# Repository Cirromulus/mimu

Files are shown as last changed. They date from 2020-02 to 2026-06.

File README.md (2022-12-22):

# Microphone Mute
Range Sensor for auto-muting a microphone when not in use.

## Description
On stage, noise level is high. A gate on the mics is sometimes not sufficient.
This device is intended to be mounted directly on the back of the mic, sensor facing towards mic.
The trigger-distance is adjustable by pressing the top button.
Also, by double-pressing this button, different mute-profiles will be selectable where choices can be the on- or the off-ramp time, and the dampening (gate/expander) in "mute" mode (testing required).

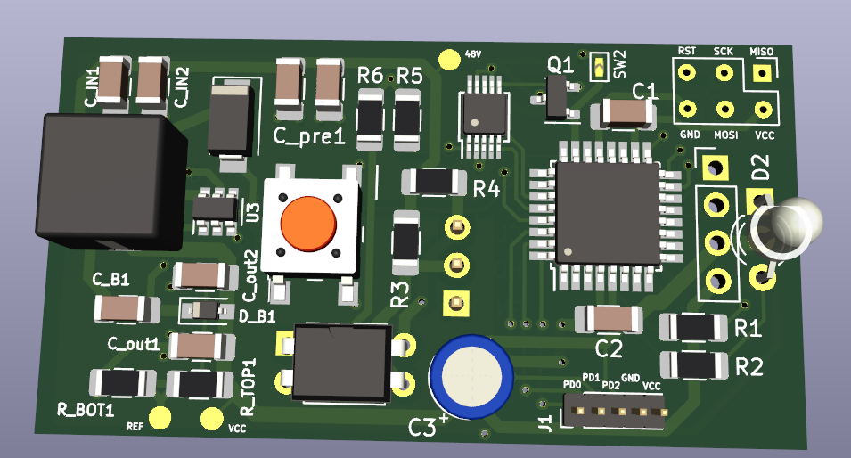
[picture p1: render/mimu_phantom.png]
phantom


## BOM
Main Features:
- ATtiny88 Processor
- GY-530 IR TOF Distance Sensor (VL53L0X)
- PC817 Optocoupler as an attenuator
- AD5258 digi-potentiometer as a variable current control for the Opto

For complete list, see [BOM](pcb/mimu_phantom_bom.html)

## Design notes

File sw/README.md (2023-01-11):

framework-arduino-avr-attiny needs patching if less RAM is desired:

Go to your version of platformio packages (most likely `/home/$(whoami)/.platformio/packages/framework-arduino-avr-attiny`) and apply the patch there (`git apply path-to-patch`).

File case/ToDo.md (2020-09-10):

Für V1:
- X Poti Position passt nicht 
- X Spiel Batteriefach sehr gering, etwas erhöhen
- X Statt Fenster vorne jew ein Loch für Tof und LED, und diese etwas höher als ursprüngliches Fenster
- X Tof weiter nach vorne setzen, Tasche innen dort kleiner
-(X) Verbinder aus dem Weg bei Kabeln->erhöhen. Am besten schraube nach oben rechts versetzen wegen Spaltmaße
- X Durchmesser Verbinder erhöhen, fallen nach und nach vom Rest ab
- X Innendurchmesser ring etwas größer 0,2 oder so
- (X) Nut und Feder für Deckel <- wackelig
- X Tasche im Deckel für Batteriefach Verbreitern, damit das auch passt
- (X) Außerdem Platine etwas "höher" setzen, damit das auch in der Tiefe wirklich passt [-> nächstes Design]
- X Wandstärke Deckel doch wieder etwas hoch, sehr wabbelig
- X Kanten außen alle etwas abrunden
- X Durchmesser Durchgangslöcher noch etwas größer, schrauben bleiben stecken
- X Spiel Schalter leicht geringer
- X Hinteren Stecker etwas weiter raus, weil sonst Konterschrauben mit Innenleben nicht mehr passen

Für V2:
- in zukünfitger Version metallene Einbaubuchse von HiCon nehmen?
- Allgemeinen Parameter für Spiel
- Wichtige Parameter im Zentralteil anlegen
- Gehäuse aufbauen um Stecker / ToF herum

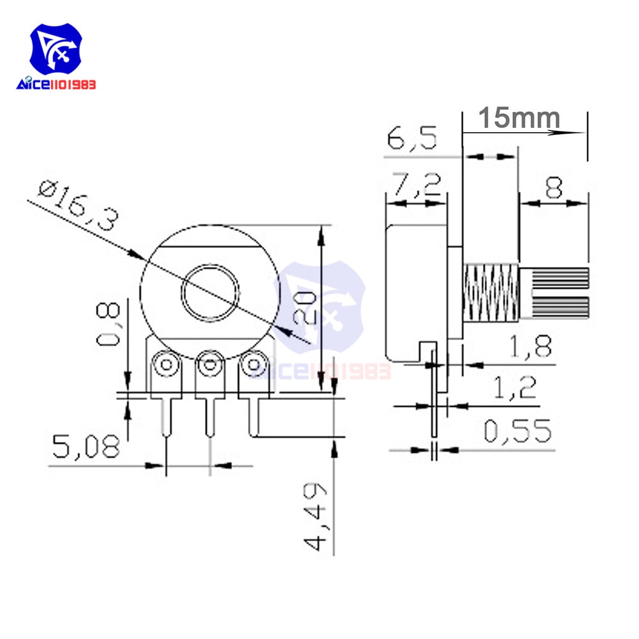
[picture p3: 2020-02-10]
doc/5-PCS-Lot-Potentiometer-Resistor-1K-2K-5K-10K-20K-50K-100K-500K-Ohm-3-Pin.jpg

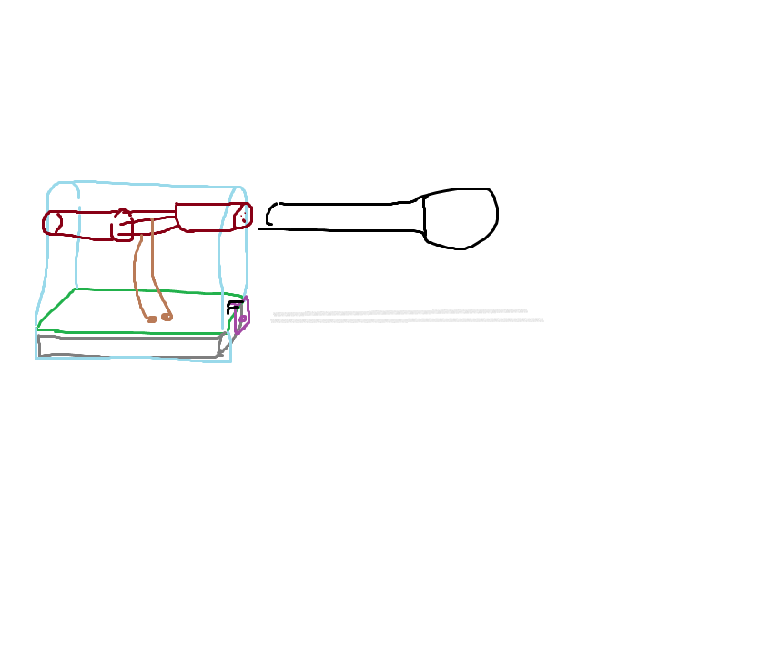
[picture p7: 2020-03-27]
case/totally_accurate_drawing.png

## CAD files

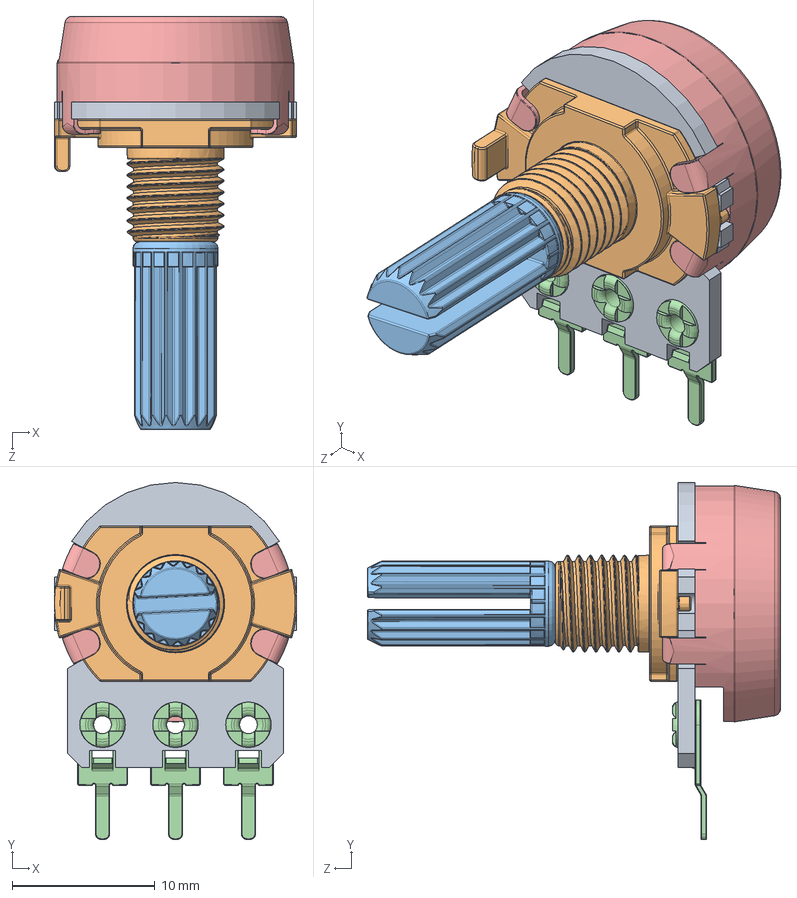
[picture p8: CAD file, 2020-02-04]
pcb/3dFiles/Assem1.SLDASM
17.0 x 25.1 x 29.0 mm
pcb board
base metal
rotating rod metal
pin x 3
sheild metal
plastic base

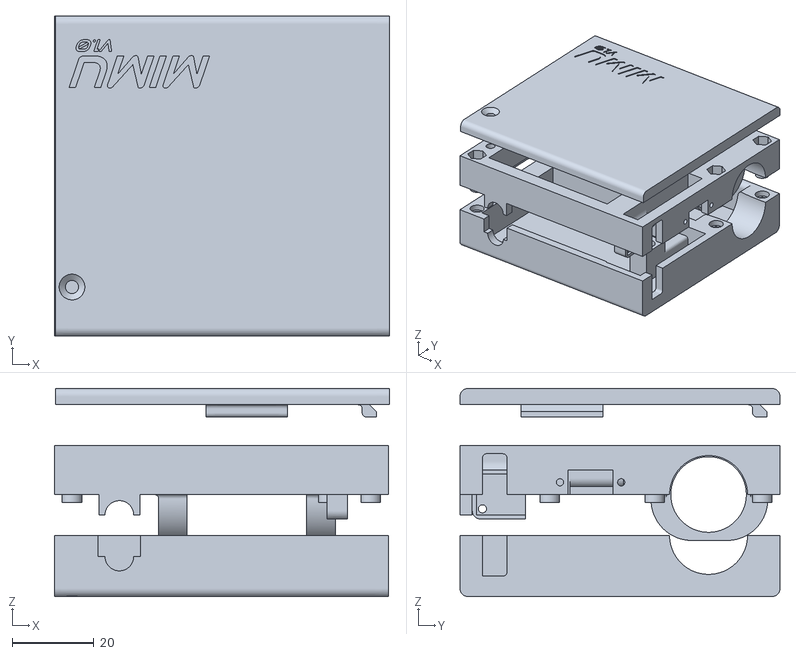
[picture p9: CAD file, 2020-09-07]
case/AssemblyV1.stl
82.1 x 78.4 x 51.0

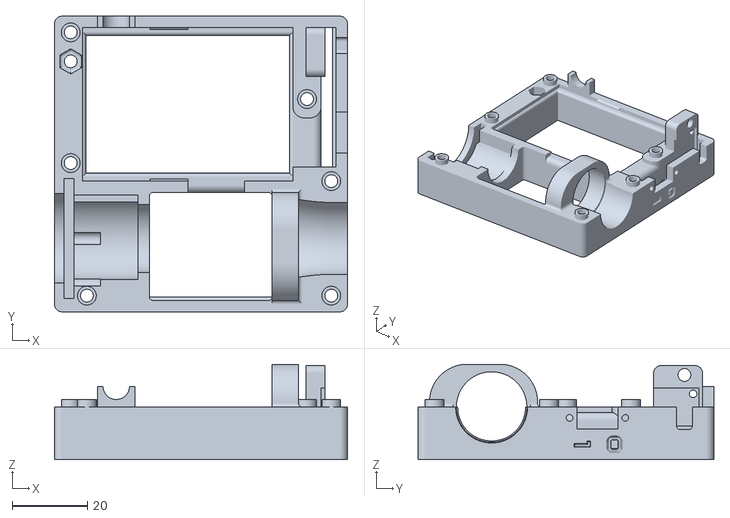
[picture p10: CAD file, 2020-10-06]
case/Gehause_A_neu_Buchse.stl
77.8 x 78.5 x 25.4

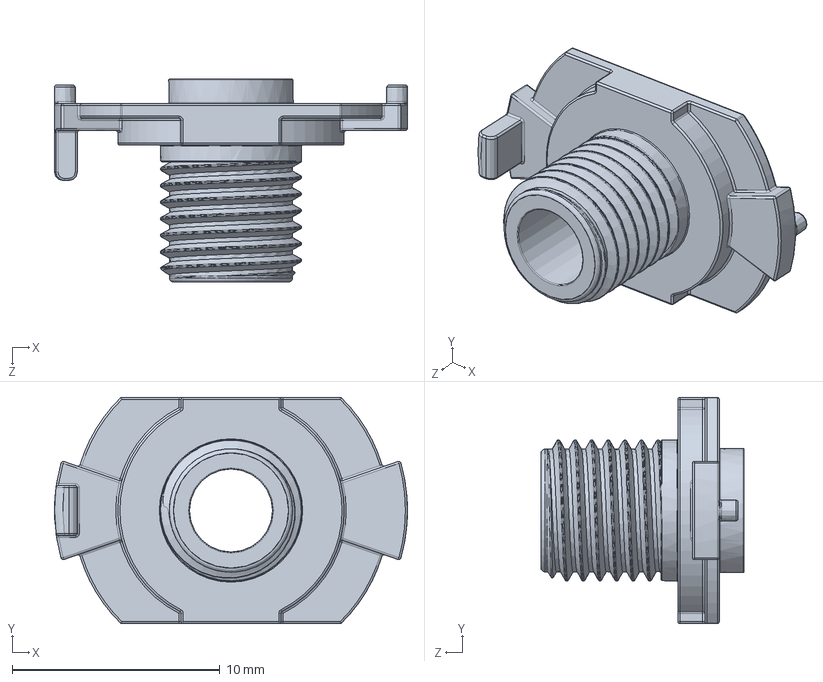
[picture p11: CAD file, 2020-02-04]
pcb/3dFiles/base metal.SLDPRT
17.0 x 10.9 x 9.80 mm

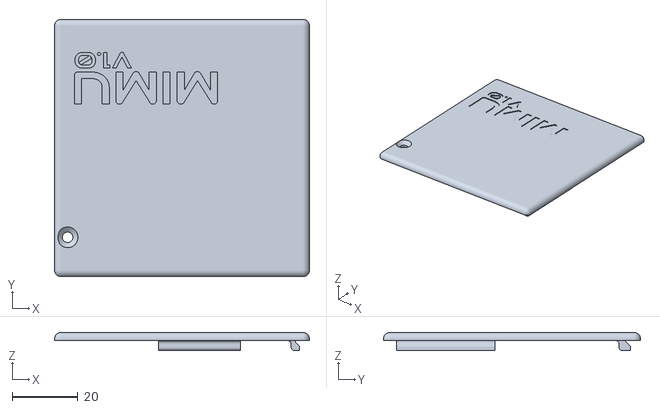
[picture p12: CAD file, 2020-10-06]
case/Deckel.stl
77.8 x 78.5 x 5.50

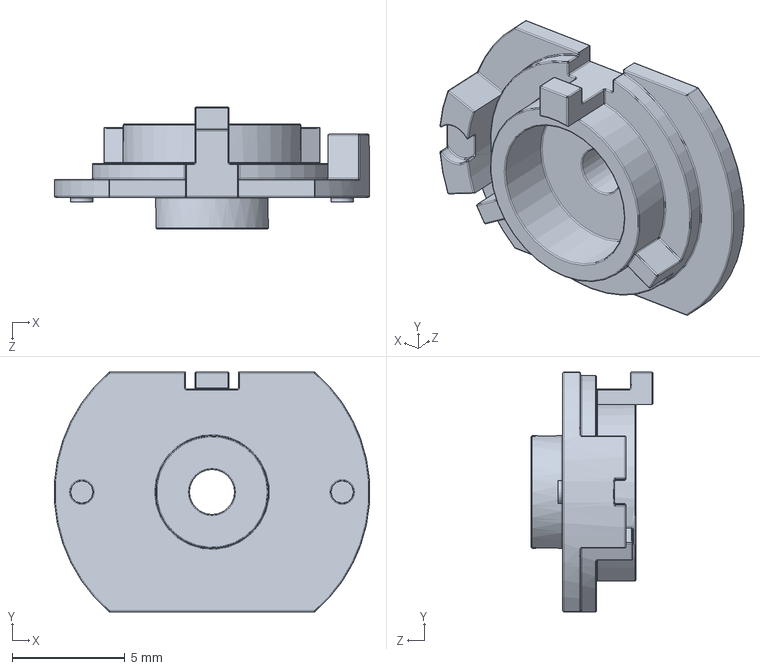
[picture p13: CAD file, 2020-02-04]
pcb/3dFiles/plastic base.SLDPRT
14.0 x 10.6 x 5.40 mm

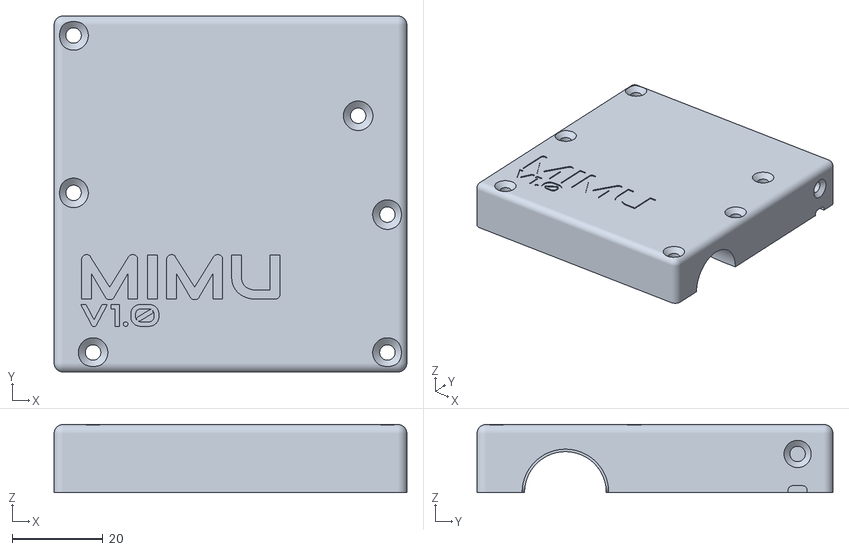
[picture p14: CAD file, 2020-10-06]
case/Gehause_B_Buchse.stl
77.8 x 78.5 x 15.0

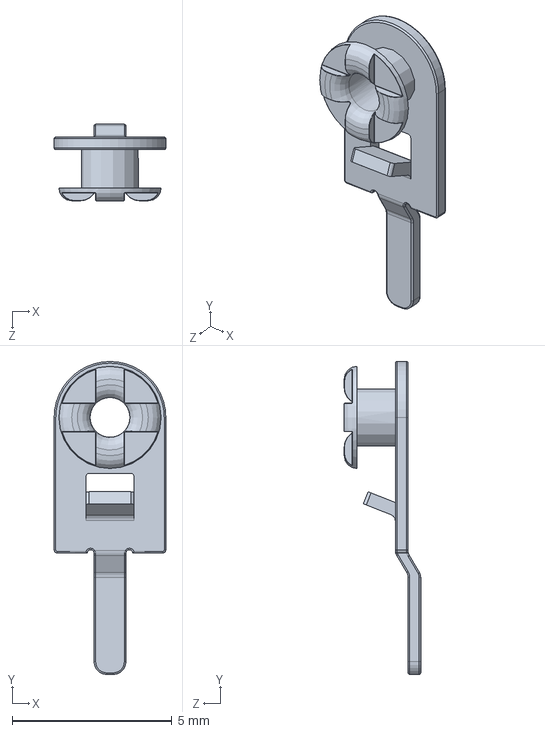
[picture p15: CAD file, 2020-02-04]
pcb/3dFiles/pin.SLDPRT
3.50 x 9.80 x 2.40 mm

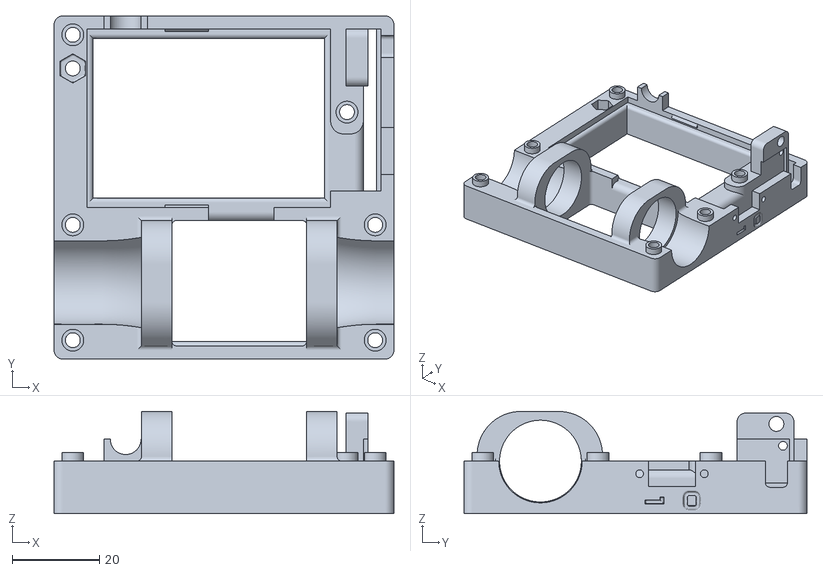
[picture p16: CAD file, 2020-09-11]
case/Gehause_A_neu.stl
77.8 x 78.5 x 23.4

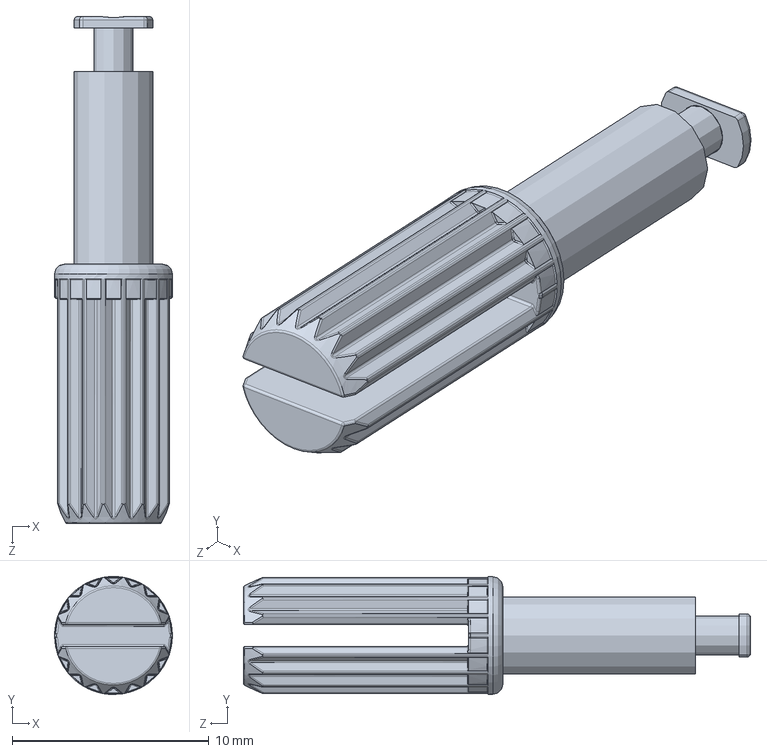
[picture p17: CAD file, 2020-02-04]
pcb/3dFiles/rotating rod metal.SLDPRT
6.00 x 6.00 x 25.8 mm

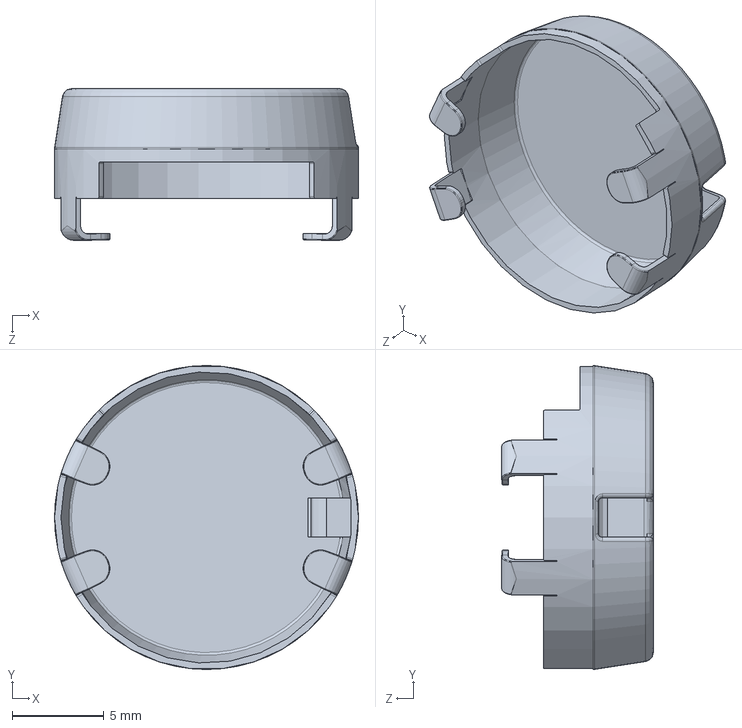
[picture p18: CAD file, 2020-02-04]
pcb/3dFiles/sheild metal.SLDPRT
16.6 x 16.6 x 8.28 mm

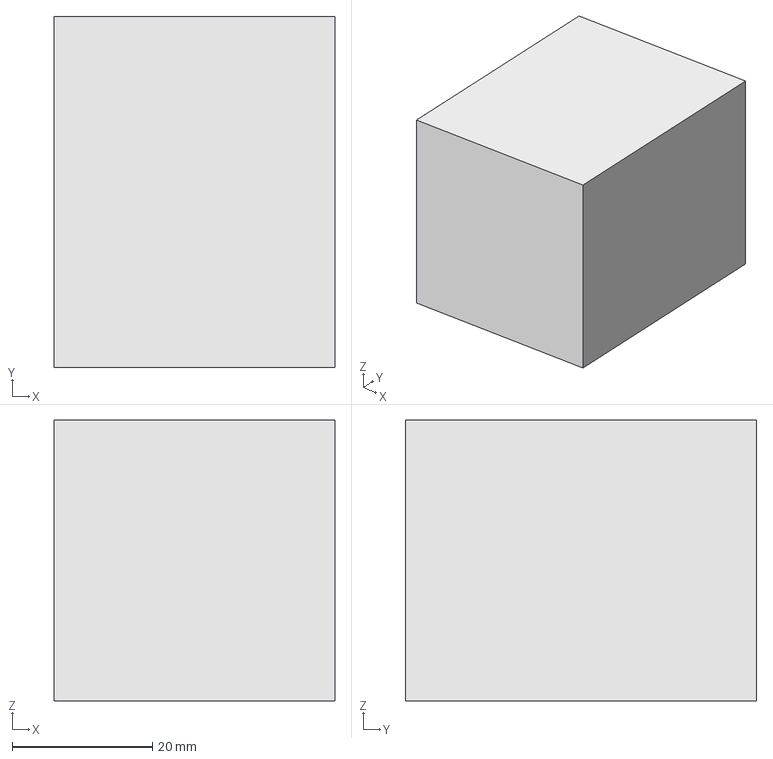
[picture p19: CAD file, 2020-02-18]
case/test.FCStd
40.0 x 50.0 x 40.0 mm

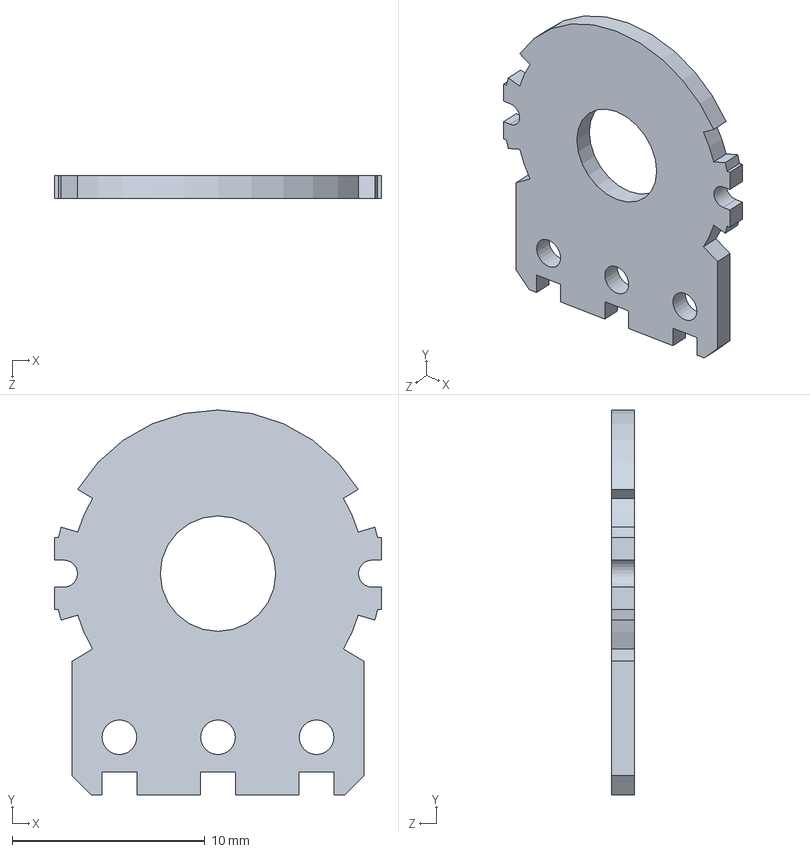
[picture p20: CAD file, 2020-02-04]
pcb/3dFiles/pcb board.SLDPRT
17.0 x 20.0 x 1.20 mm

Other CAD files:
case/Gehause_B.stl

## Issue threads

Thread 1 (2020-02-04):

Schematic & PCB Rendering not easily accessible

cajt, 2020-02-04:
A bitmap export of the Kicad project might make the data more accessible.

Cirromulus, 2020-02-05:
Hi Carl :)
Do you mean something additional to the PCB rendering in /render/board3d.png?
It should be included in the Readme.md .

cajt, 2020-02-07:
The new /render/schematic.png does the job well, and it is way more comfortable that cloning and loading Kicad in the correct version. Thanks!

Closed 2020-02-07.

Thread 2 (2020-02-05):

Button needed

Cirromulus, 2020-02-05:
Sometimes the user may want to deactivate the system without having to disconnect the Batteries.

Cirromulus, 2020-02-12:
added switch breaker

Closed 2020-02-12.

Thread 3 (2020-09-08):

Add automatic calibration routine upon startup

Hackbraten, 2020-09-08:
The Potentiometer is cool and swifty (nice bro that had this idea), but not very user intuitive.
Maybe we reduce the power of the people and just add an automatic calibration routine in startup, that estimates the threshold distance (plus some margin).

Less user errors, less BOM. And BOM is everything.

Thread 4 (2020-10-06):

implement "auto off" function for power saving?

Hackbraten, 2020-10-06:
maybe after x minutes of same tof value or something

Cirromulus, 2020-10-06:
While this is technically possible, I am unsure if a wakeup-latency of ~1s is acceptable on stage.
If this is wanted, an implementation would be feasible.

Cirromulus, 2020-10-06:
While this is technically possible, I am unsure if a wakeup-latency of ~1s is acceptable on stage.
If this is wanted, an implementation would be feasible.

Closed 2020-10-24.

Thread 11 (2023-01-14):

Allow multiple Mute Profiles

Cirromulus, 2023-01-14:
In EEPROM.
How to switch them?
- Double-press button

How to set them?
- Tiny PCB switches, future NFC?

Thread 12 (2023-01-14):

Correct Pad size for Button

Cirromulus, 2023-01-14:
Button is solderable, but pads are a bit not-far apart.

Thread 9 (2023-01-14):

[PCB] Add cap to extra_drive MOSFET output

Cirromulus, 2023-01-14:
The switching Mosfet causes a (faint) cracking noise in Microphone audio.
Perhaps reduce ramp-on time (off time seems ok)

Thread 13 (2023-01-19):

Current draw too high for Phantom Supply

Cirromulus, 2023-01-19:
High draw of Optocoupler is too much.
Even with R_phantom at 1kOhm, supply from Mixing Console is not enough.

Solutions:
- Use more expensive, but less power-hungry Optocoupler `NSL-32SR3`
- Switch to virtual Ground supply (with, perhaps, Opamp `ADA4099-1BUJZ-RL7`) and directly use Digipot (which then has to be higher resistance and logarithmic)

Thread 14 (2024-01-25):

Caustics

tradephonic, 2024-01-25:
Hi there, really sorry to open an issue on an unrelated repo. I was wondering if you could enable issues on https://github.com/Cirromulus/causticsEngineering if you are still willing/able to fix bugs for it. I have been testing the caustics it produces in Blender and found a couple of issues. These issues are not found in the original script from Matt Ferraro. I am really eager to get your script working as I think it will produce better quality caustics. Thanks in advance.

Cirromulus, 2024-01-25:
Uhm, yes I now have enabled Issues there. The project is quite old, though.

Closed 2024-01-25.

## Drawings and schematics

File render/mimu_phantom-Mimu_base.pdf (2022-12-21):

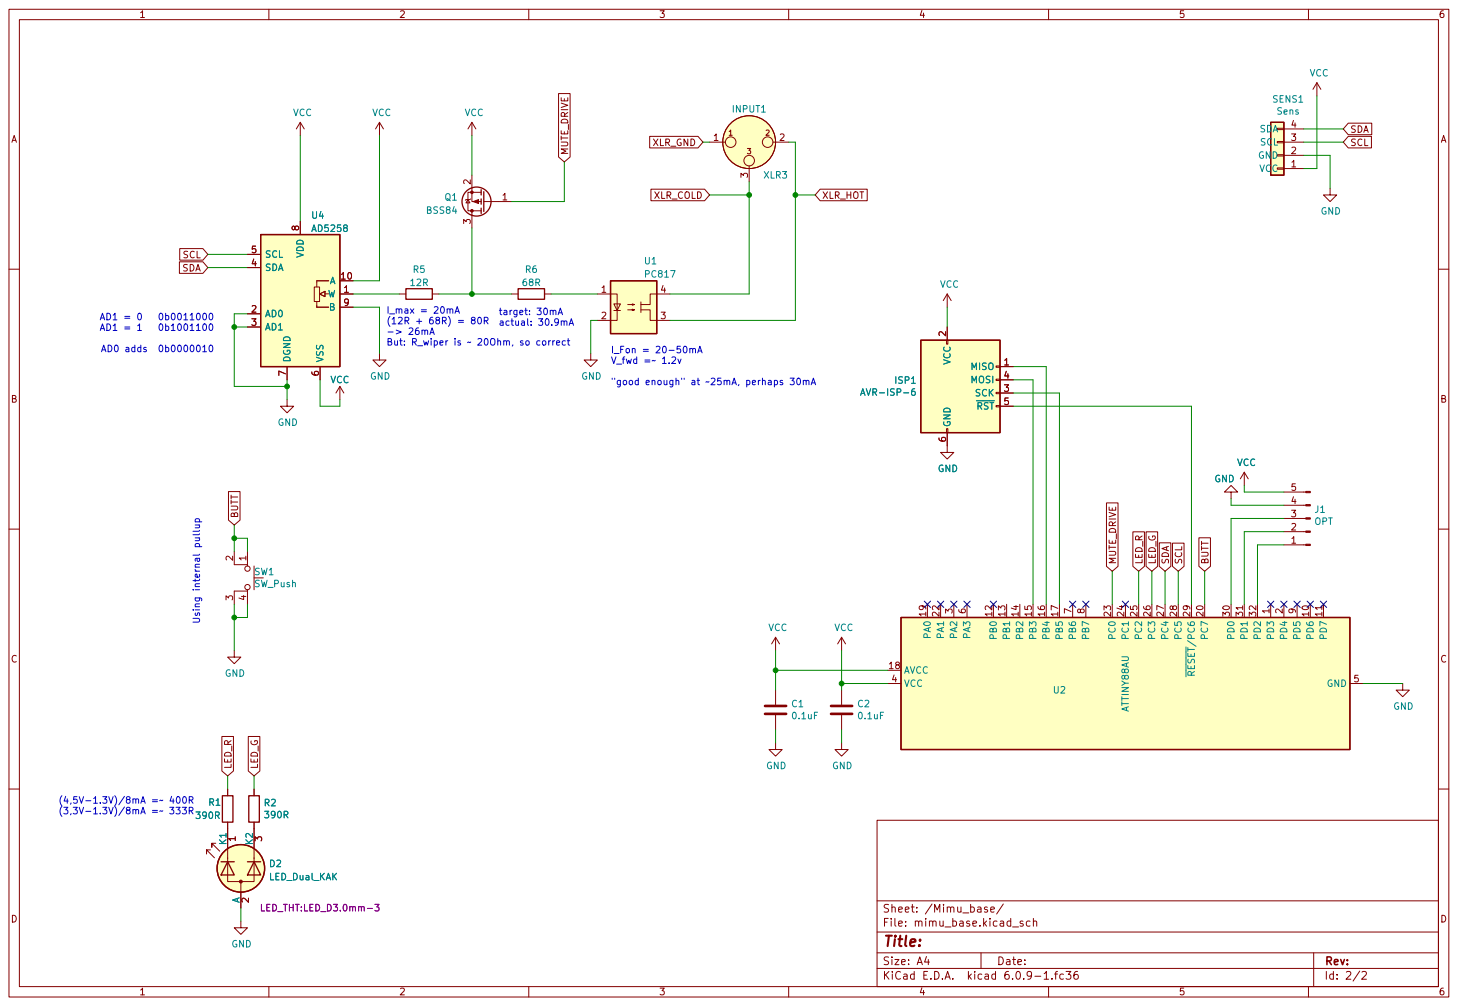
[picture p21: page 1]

2 SCK 3 MOSI 4 ~{RST} 5 GND

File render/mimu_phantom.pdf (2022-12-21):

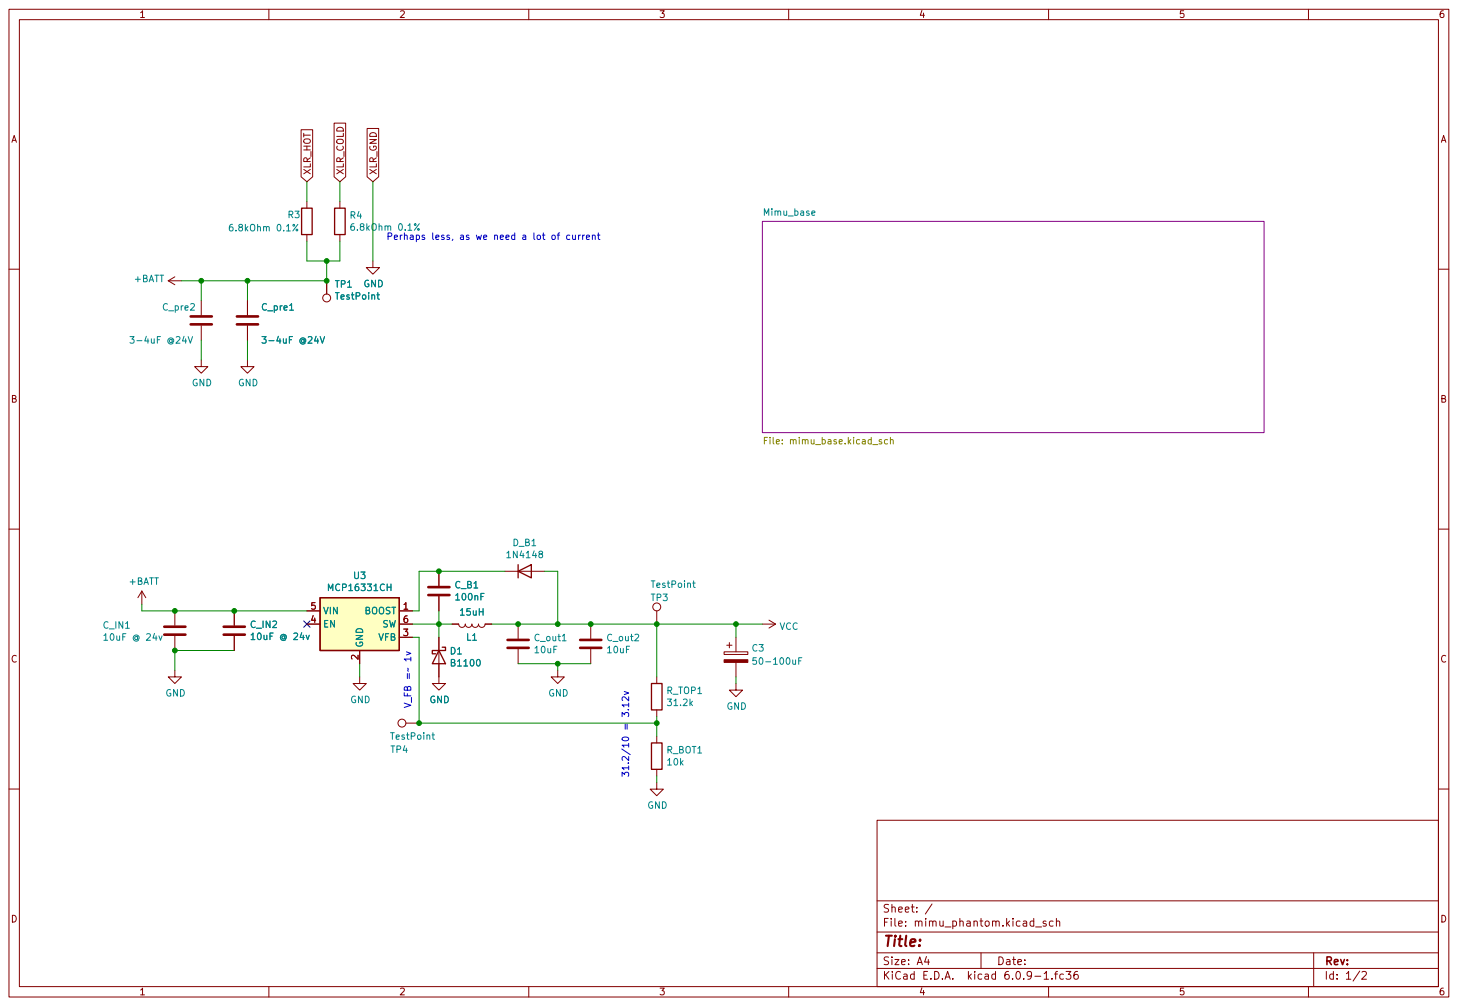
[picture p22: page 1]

2 VFB 3 EN 4 VIN 5 SW 6 U3 MCP16331CH +BATT GND

2 VFB 3 EN 4 VIN 5 SW 6


2 SCK 3 MOSI 4 ~{RST} 5 GND

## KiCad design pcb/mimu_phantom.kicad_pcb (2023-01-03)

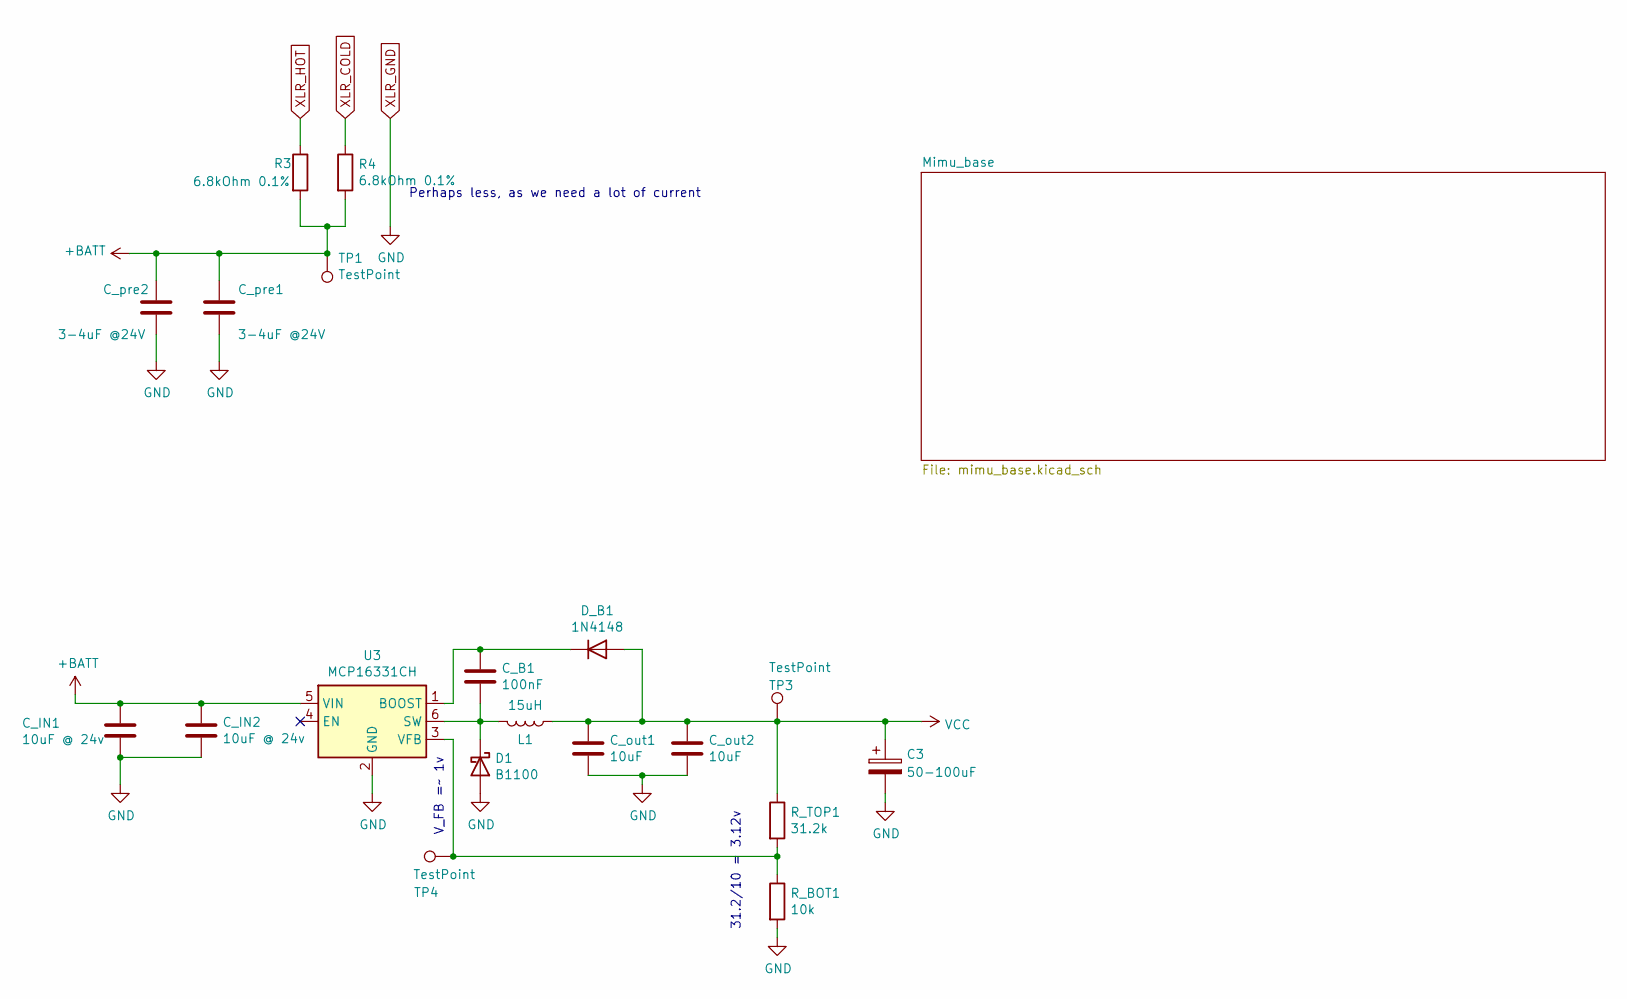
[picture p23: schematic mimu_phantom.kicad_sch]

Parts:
C3: 50-100uF; CP_Radial_D5.0mm_P2.00mm
C_B1: 100nF; C_1206_3216Metric_Pad1.42x1.75mm_HandSolder
C_IN1, C_IN2: 10uF @ 24v; C_1206_3216Metric_Pad1.42x1.75mm_HandSolder
C_out1, C_out2: 10uF; C_1206_3216Metric_Pad1.42x1.75mm_HandSolder
C_pre1, C_pre2: 3-4uF @24V; C_1206_3216Metric_Pad1.33x1.80mm_HandSolder
D1: B1100; D_SMA
D_B1: 1N4148; D_SOD-323_HandSoldering
L1: 15uH; L_7.3x7.3_H4.5
R3, R4: 6.8kOhm 0.1%; R_1206_3216Metric_Pad1.30x1.75mm_HandSolder
R_BOT1: 10k; R_1206_3216Metric_Pad1.42x1.75mm_HandSolder
R_TOP1: 31.2k; R_1206_3216Metric_Pad1.42x1.75mm_HandSolder
TP1, TP3, TP4: TestPoint; Measurement_Point_Round-SMD-Pad_Small
U3: MCP16331CH; SOT-23-6

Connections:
+BATT: C_IN1.1, C_IN2.1, C_pre1.1, C_pre2.1, R3.2, R4.2, TP1.1, U3.5 (VIN)
unnamed: C_B1.1, D_B1.1 (K), U3.1 (BOOST)
unnamed: C_B1.2, D1.1 (K), L1.2, U3.6 (SW)
unnamed: R_BOT1.1, R_TOP1.2, TP4.1, U3.3 (VFB)
VCC: C3.1, C_out1.1, C_out2.1, D_B1.2 (A), L1.1, R_TOP1.1, TP3.1; also elsewhere on the board
XLR_COLD: R4.1; also elsewhere on the board
XLR_GND: C3.2, C_IN1.2, C_IN2.2, C_out1.2, C_out2.2, C_pre1.2, C_pre2.2, D1.2 (A), R_BOT1.2, U3.2 (GND); also elsewhere on the board
XLR_HOT: R3.1; also elsewhere on the board

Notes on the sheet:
31.2/10 = 3.12v
Perhaps less, as we need a lot of current
V_FB =~ 1v

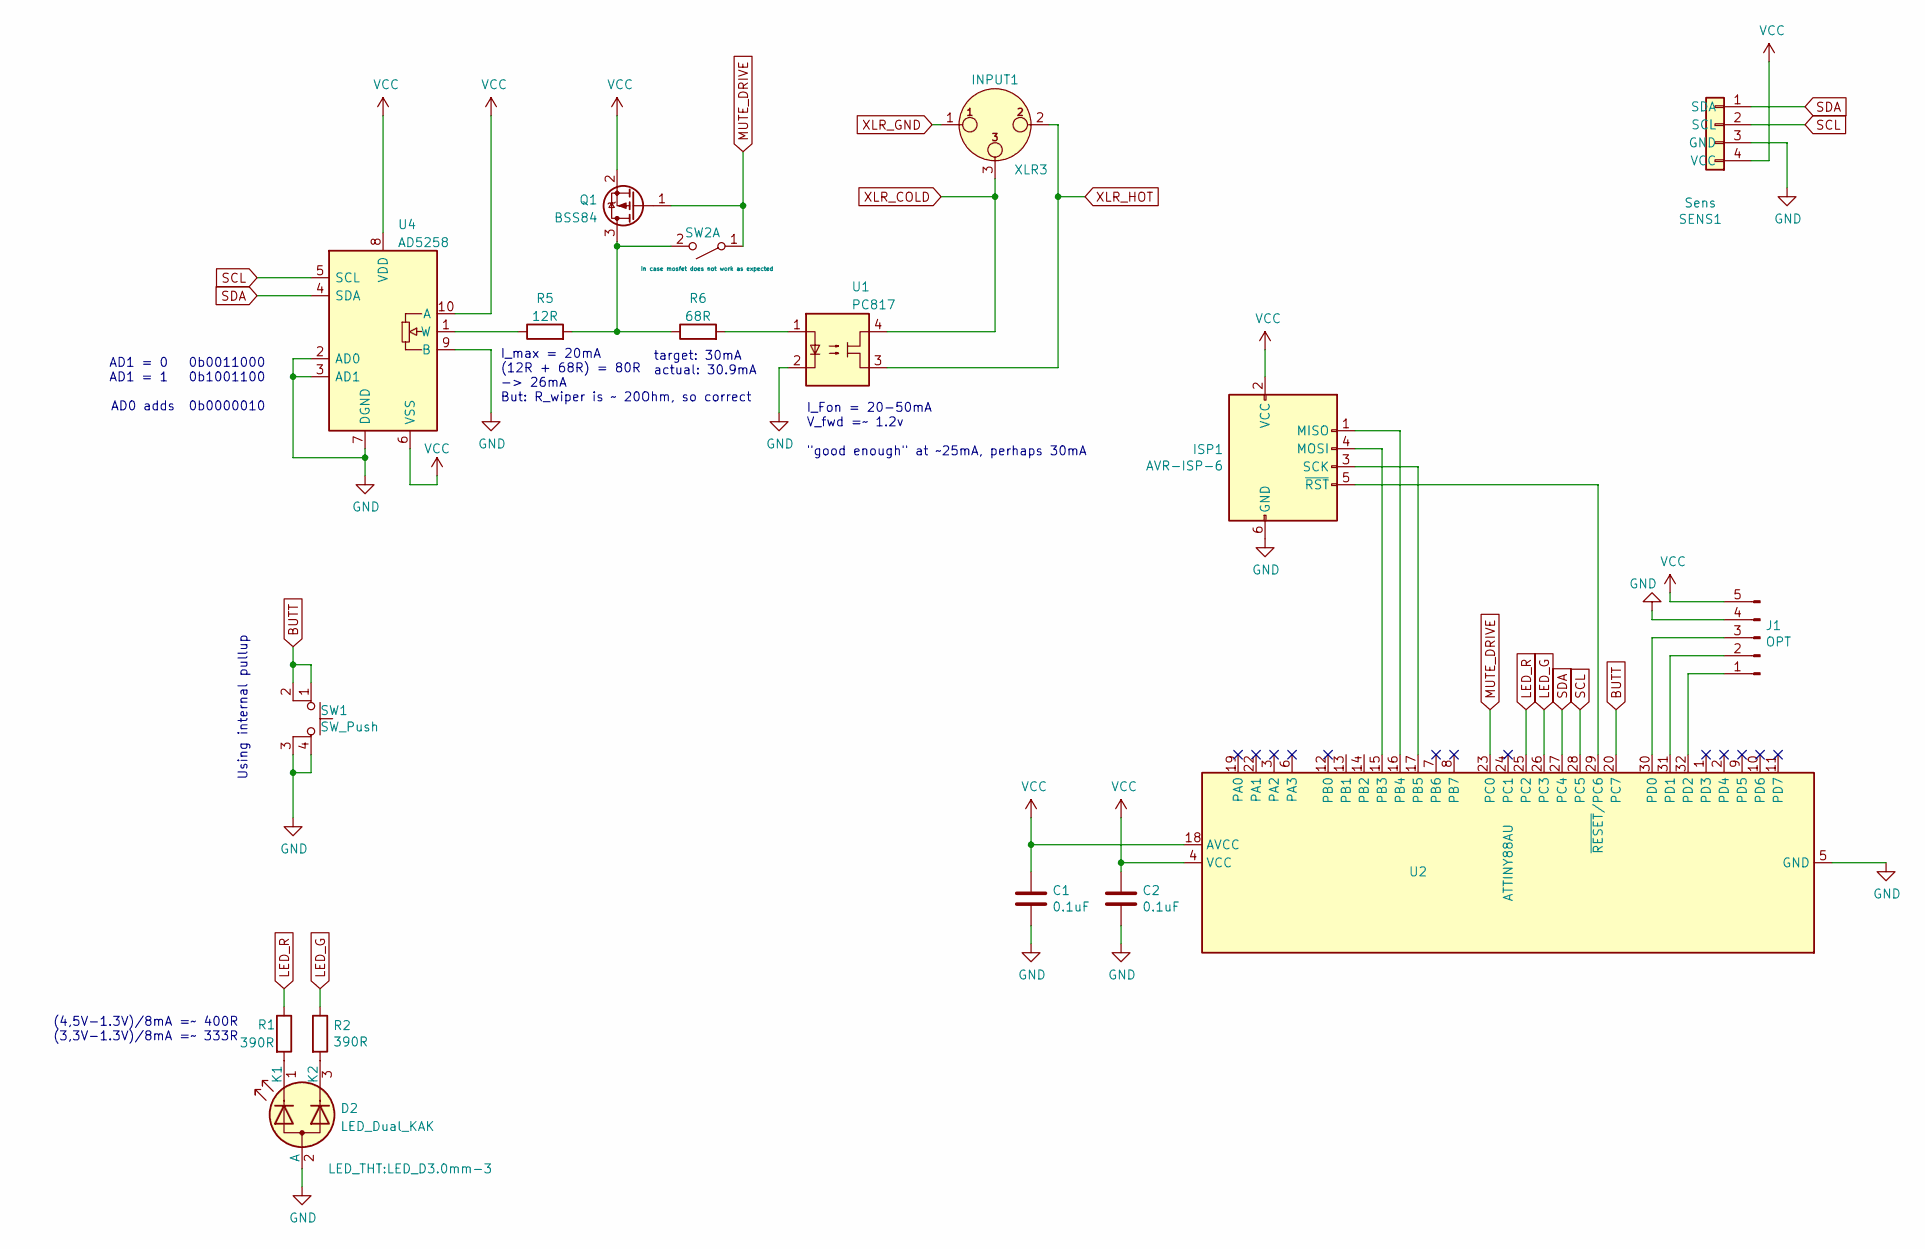
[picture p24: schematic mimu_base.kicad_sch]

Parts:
C1, C2: 0.1uF; C_1206_3216Metric_Pad1.33x1.80mm_HandSolder
D2: LED_Dual_KAK; LED_D3.0mm-3
INPUT1: XLR3; PinHeader_1x03_P2.54mm_Vertical
ISP1: AVR-ISP-6; PinHeader_2x03_P2.54mm_Vertical_pogo
J1: OPT; PinHeader_1x05_P1.27mm_Vertical
Q1: BSS84; SOT-23
R1: 390R; C_1206_3216Metric_Pad1.33x1.80mm_HandSolder
R2: 390R; R_1206_3216Metric_Pad1.30x1.75mm_HandSolder
R5: 12R; R_1206_3216Metric_Pad1.30x1.75mm_HandSolder
R6: 68R; R_1206_3216Metric_Pad1.30x1.75mm_HandSolder
SENS1: Sens; PinHeader_1x04_P2.54mm_Vertical
SW1: SW_Push; Switch_Tactile_SMD_6x6mm_PTS645
SW2: In case mosfet does not work as expected; SolderJumper-2_P1.3mm_Open_TrianglePad1.0x1.5mm
U1: PC817; DIP-4_bubble_W7.62mm
U2: ATTINY88AU; TQFP-32_7x7mm_P0.8mm
U4: AD5258; MSOP-10_3x3mm_P0.5mm

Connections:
BUTT: SW1.1, SW1.2, U2.20 (PC7)
LED_G: R2.1, U2.26 (PC3)
LED_R: R1.1, U2.25 (PC2)
MUTE_DRIVE: Q1.1 (G), SW2.1 (A), U2.23 (PC0)
unnamed: D2.1 (K1), R1.2
unnamed: D2.3 (K2), R2.2
unnamed: ISP1.1 (MISO), U2.16 (PB4)
unnamed: ISP1.3 (SCK), U2.17 (PB5)
unnamed: ISP1.4 (MOSI), U2.15 (PB3)
unnamed: ISP1.5 (~RST), U2.29 (~RESET/PC6)
unnamed: J1.1, U2.32 (PD2)
unnamed: J1.2, U2.31 (PD1)
unnamed: J1.3, U2.30 (PD0)
unnamed: R5.1, U4.1 (W)
unnamed: R6.2, U1.1
unnamed: Q1.3 (D), R5.2, R6.1, SW2.2 (B)
SCL: SENS1.2 (SCL), U2.28 (PC5), U4.5 (SCL)
SDA: SENS1.1 (SDA), U2.27 (PC4), U4.4 (SDA)
VCC: C1.1, C2.1, ISP1.2 (VCC), J1.5, Q1.2 (S), SENS1.4 (VCC), U2.4 (VCC), U2.18 (AVCC), U4.6 (VSS), U4.8 (VDD), U4.10 (A); also elsewhere on the board
XLR_COLD: INPUT1.3, U1.4; also elsewhere on the board
XLR_GND: C1.2, C2.2, D2.2 (A), INPUT1.1, ISP1.6 (GND), J1.4, SENS1.3 (GND), SW1.3 (K), SW1.4 (A), U1.2, U2.5 (GND), U2.21 (GND), U4.2 (AD0), U4.3 (AD1), U4.7 (DGND), U4.9 (B); also elsewhere on the board
XLR_HOT: INPUT1.2, U1.3; also elsewhere on the board

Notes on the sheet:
Using internal pullup
I_max = 20mA (12R + 68R) = 80R -> 26mA But: R_wiper is ~ 20Ohm, so correct
I_Fon = 20-50mA V_fwd =~ 1.2v "good enough" at ~25mA, perhaps 30mA
AD1 = 0 0b0011000 AD1 = 1 0b1001100 AD0 adds 0b0000010
target: 30mA actual: 30.9mA
(4,5V-1.3V)/8mA =~ 400R (3,3V-1.3V)/8mA =~ 333R

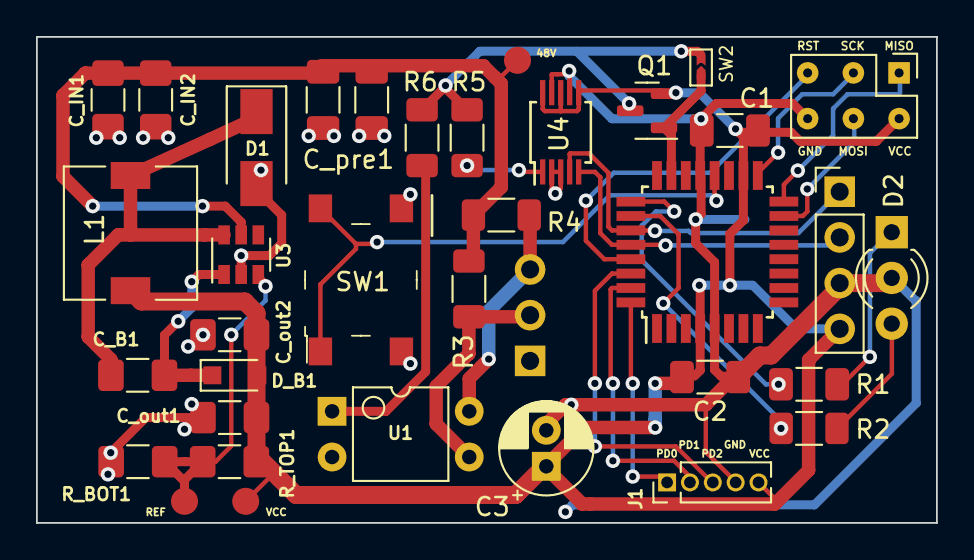
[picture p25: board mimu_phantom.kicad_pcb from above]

Board: 2 copper layers, 50.0 x 27.0 mm, 36 parts (1 on the bottom side), 26 nets.

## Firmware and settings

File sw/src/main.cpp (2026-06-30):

#include <config.hpp>
#include "userInterface.hpp"
#include "peripherals.hpp"
#include "mutehandling.hpp"
#include "sensorhandling.hpp"
#include "distanceStorage.hpp"

#include <Arduino.h>

static Mutehandling mute{};
static DistanceStorage switchingDistance;
static bool should_mute = false;
static bool isSettingDistance = false;
static uint8_t consecutive_equal_decisions = 0;
static uint8_t previousTimeOuts = 0;

void setup() {
    ui::init();
    initButton();
    initDebugLines();

    if constexpr (has_serial)
    {
        Serial.begin(115200);
        while (!Serial) {
            ui::waitingForSerial();
        }
    }
    else
    {
        ui::switchOn();
    }

    switchingDistance.loadFromEeprom();

    Wire.begin();
    Wire.setClock(100000);  // or 400000

    while(!mute.initDigipotUnmuted()) {
        ui::digipotCommunicationError();
    }

    initSensor();
    startMeasuring();

    ui::ready();
}

void loop() {
    bool previous_measurement_was_muted = should_mute;

    if constexpr (has_serial)
        if (Serial) Serial.println("Measuring...");

    const Distance_mm measured_distance_mm = sensor.readRangeContinuousMillimeters();
    if (sensor.timeoutOccurred()) {
        // Communication with Sensor did not succeed
        if(previousTimeOuts < CONSECUTIVE_TIMEOUTS_WARNING) {
            // do not blink error code yet
            previousTimeOuts++;
        } else {
            ui::sensorCommunicationError();
            ui::muted(should_mute); // ui function does not reset LED state
        }
        // Do not use the time-out measurement
        return;
    } else {
        // No timeout, so reset counter
        previousTimeOuts = 0;
    }

    // ---- set distance ----

    if (getButton()) {
        // unmute, but only once
        if(should_mute) {
            should_mute = false;
            mute.setMute(should_mute);
        }
        
        ui::settingDistance();
        isSettingDistance = true;
        switchingDistance.set(measured_distance_mm);
        return;
    } else {
        if (isSettingDistance)
        {
            // button pressing ended. Store to eeprom.
            switchingDistance.storeToEeprom();
            isSettingDistance = false;
            // "restore" state and also blink "success"
            ui::settingDistance(false);
        }
    }

    // ----

    // Decide if we should mute
    if(!previous_measurement_was_muted) {
        // was "on"
        if (measured_distance_mm > DEADZONE_LOW_MM) {
            //debounce
            should_mute = measured_distance_mm > (switchingDistance.get_mm() + DEBOUNCE_RANGE_MM);
        } else {
            // if lower than deadzone, no update happens
        }
    } else {
        // was "off"
        should_mute = measured_distance_mm > switchingDistance.get_mm();
    }

    // handle filtering counter
    if constexpr (FILTER_EQUAL_DECISIONS_NEEDED > 1) {
        if(previous_measurement_was_muted != should_mute) {
            consecutive_equal_decisions = 1;
        } else {
            if (consecutive_equal_decisions < FILTER_EQUAL_DECISIONS_NEEDED)
                consecutive_equal_decisions++;
        }
    }

    if constexpr (has_serial) {
        if (Serial)  {
            Serial.println("Measuring...");
            Serial.print(measured_distance_mm);
            Serial.print(" > ");
            Serial.print(switchingDistance.get_mm());
        }
    }

    // execute muting decision
    if (FILTER_EQUAL_DECISIONS_NEEDED > 1 && consecutive_equal_decisions < FILTER_EQUAL_DECISIONS_NEEDED) {
        // not yet enough equal measurements, stick to the "old" value
    } else {
        //waitForButtonPress(3);
        if(previous_measurement_was_muted != should_mute) {
            //waitForButtonPress(4);
            mute.setMute(should_mute);
        }
    }
}

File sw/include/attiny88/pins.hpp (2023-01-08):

#include <inttypes.h>
#include <Arduino.h>

static constexpr uint8_t MUTE_DRIVE = 17;   //PC0
static constexpr uint8_t BUTTON     = 16;   //PC7
static constexpr uint8_t LEDG       = 19;   //PC2
static constexpr uint8_t LEDR       = 20;   //PC3
static constexpr uint8_t J0   = 0;
static constexpr uint8_t J1   = 1;
static constexpr uint8_t J2   = 2;

static constexpr bool has_serial = false;

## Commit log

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2020-02-04 Updated to using new low R_on optocoupler
    [mimu3000.kicad_pcb, mimu3000.sch]
2020-02-04 Fixed courtyard
    [mimu3000.kicad_pcb]
2020-02-04 Added jumper for demo
    [mimu3000.kicad_pcb]
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2020-02-05 Initial Test for soft I2C
    [Assem1.SLDASM, base metal.SLDPRT, mimu3000.kicad_pcb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]
2020-02-05 Soft I2C uses 3.7 times the available progmem.
2020-02-06 Switched to attiny48
    [mimu3000.kicad_pcb, mimu3000.sch]
2020-02-06 Now using attiny48 (88 for memory analysis, PIO sucks)
    [mimu3000.kicad_pcb, mimu3000.sch]
2020-02-07 Capacitance needed?
    [mimu3000.sch]
2020-02-07 Still too much progmem
    [mimu3000.kicad_pcb]
2020-02-07 We have to use Attiny88
    [mimu3000.kicad_pcb, mimu3000.sch]
2020-02-07 Added 3 extra IO
    [mimu3000.kicad_pcb, mimu3000.sch]
2020-02-10 Use realworld-potentiometer
    [mimu3000.kicad_pcb, mimu3000.sch]
2020-02-11 Switched to 3xAAA container, Vertically fixed Sensor and the possibility to adding a tantal for de-pop
    [mimu3000.kicad_pcb, mimu3000.sch]
2020-02-11 added JCL number placeholder
    [mimu3000.kicad_pcb]
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2020-02-17 Missed something
    [mimu3000.kicad_pcb]
2020-02-17 Use electrolyte caps
    [mimu3000.kicad_pcb, mimu3000.sch]
2020-02-18 Flipped Sensor to save space
    [mimu3000.kicad_pcb, mimu3000.sch]
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2020-02-18 Gerber files of Version 0.4
    [mimu3000-B_Cu.gbr, mimu3000-B_Mask.gbr, mimu3000-B_Paste.gbr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]
2020-02-18 Added placeholder for case
    [test.FCStd]
2020-03-09 Fixed wrong-sized pitch of sensor, corrected witdh of a track. easier footprint for opto
    [mimu3000.kicad_pcb, mimu3000.sch]
2020-03-10 Fixed misconception that a Capacitor before Opto would smooth the curve
    [mimu3000.kicad_pcb, mimu3000.sch]
2020-03-12 divided schematics to hierarchically have battery and phantom powered variant
    [mimu3000.csv, mimu3000.sch, mimu_base.sch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]
2020-03-12 I hope this did not break everything
    [mimu_base.sch, mimu_batt.sch, mimu_phantom.kicad_pcb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]
2020-03-13 Quick layout test
    [mimu_base.sch, mimu_phantom.kicad_pcb, mimu_phantom.sch]
2020-03-14 Now it just has to work, lol
    [mimu_base.sch, mimu_phantom.kicad_pcb, mimu_phantom.sch]
2020-03-17 Dey see me layoutin', dey hatin'
    [mimu_phantom.kicad_pcb]
2020-03-17 Buy all the shit
    [mimu_base.sch, mimu_phantom.kicad_pcb, mimu_phantom.sch]
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2020-03-26 Increased Warning Voltage And fixed bug in warning blink
    [main.cpp]
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2020-03-27 Bump near-final version for battery powered version. Todo: Maybe remove the capacitor? Needs realworld-test.
    [mimu_base.sch, mimu_batt.kicad_pcb]
2020-03-27 Quick order of some pcbs
    [mimu3000-B_Mask.gbr, mimu3000-B_Paste.gbr, mimu3000-B_SilkS.gbr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]
2020-04-14 Batch 2
    [mimu_batt-B_Cu.gbr, mimu_batt-B_Mask.gbr, mimu_batt-B_Paste.gbr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]
2020-04-14 Batch 1
    [mimu_batt-NPTH.drl, mimu_batt-PTH.drl, mimu_phantom-NPTH.drl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]
2020-04-14 Cap not needed for XLR
    [mimu_base.sch, mimu_phantom.kicad_pcb]
2020-09-04 added first iteration of STLs for vertical MiMuBat case
    [AssemblyV1.stl, Deckel.stl, Gehause_A_neu.stl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]
2020-09-04 updated some play dimensions for better fit
    [AssemblyV1.stl, Deckel.stl, Gehause_A_neu.stl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]
2020-09-04 optimized wall thicknesses for 3d print
    [AssemblyV1.stl, Deckel.stl, Gehause_A_neu.stl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]
2020-09-06 Added 3d-Renderings of the PCB
    [mimu_batt.amf, mimu_batt.step, mimu_phantom.amf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]
2020-09-07 updated geometry. Case now allows actual placement of battery holder. Additional bug fixes and performance. Better camera.
    [AssemblyV1.stl, AssemblyV1.stp, Deckel.stl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]
2020-09-07 added stl files with higher res
    [AssemblyV1.stl, Deckel.stl, Gehause_A_neu.stl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]
2020-09-07 removed step files
    [AssemblyV1.stp, Deckel.stp, Gehause_A_neu.stp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]
2020-09-08 Ok, STL then.
    [mimu_batt.amf, mimu_batt.step, mimu_batt.stl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]
2020-09-09 updated todo.md
    [mimu_batt.ipt]
2020-09-10 improved V1, fixed tolerances, changed tof Window to 2 seperate holes, broadened lock mech. of lid, fixed batt freeplay, reduced pocket for Tof and cabling, moved output conn back for easier assembly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
    [Deckel.stl, Gehause_A_neu.stl, Gehause_B.stl]
2020-09-11 fixed problem with lid locking mechanism and optimized tof window width
    [Deckel.stl, Gehause_A_neu.stl, Gehause_B.stl]
2020-09-19 added stls for case with internal xlr male jack instead of clr plug
    [Gehause_A_neu_Buchse.stl, Gehause_B_Buchse.stl]
2020-09-23 updated stls for case with xlr socket now also fits in the lid.Also increased play of bat holder and moved tof window down .8mm
    [Deckel.stl, Gehause_A_neu_Buchse.stl, Gehause_B_Buchse.stl]
2020-10-04 optimized tolerances of XLR jack geometry
    [Gehause_A_neu_Buchse.stl, Gehause_B_Buchse.stl]
2020-10-06 optimized case and lid depth for XLR jack variant. Also bug fixes and improvements, better camera and stability.
    [Deckel.stl, Gehause_A_neu_Buchse.stl, Gehause_B_Buchse.stl]
2020-10-24 Stopped using Timer0 used by millis(), also added timeout. Fixes #4.
    [main.cpp]
2021-08-17 Something new about the PCB?
    [mimu_phantom.kicad_pcb, mimu_phantom.sch]
2021-08-30 Fixed wrong timer calculation and reduced delay&energy consumption with forgotten batt_check reset
    [main.cpp]
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2021-09-09 Added deadzone and filtering (filter is too slow)
    [main.cpp, pins.hpp]
2021-09-09 Using bug-fixed version, now timing budget can be reduced immensely
    [main.cpp]
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2021-10-17 This might actually work
    [mimu_base.sch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]
2021-10-18 Connected Attenuation to PWM-Able pin
    [mimu_base.sch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]
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2021-10-18 Re-Render for good measure.
    [mimu_base.sch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]
2021-10-24 Bugfix: Added missing filter cap on PWM output
    [mimu_base.sch, mimu_phantom.kicad_pcb]
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2022-11-20 re-structured 3D-Models so that scaling is correct
    [mimu_phantom.3mf, mimu_phantom.kicad_pcb, mimu_phantom.stl]
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2022-12-20 First impression of new v3!
    [mimu_base.kicad_sch, mimu_base.sch, mimu_batt.kicad_pcb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]
2022-12-20 First layout
    [mimu_base.kicad_sch, mimu_phantom.kicad_pcb, mimu_phantom.kicad_sch]
2022-12-21 Minor PCB updates
    [mimu_base.kicad_sch, mimu_phantom.kicad_pcb, mimu_phantom.kicad_sch]
2022-12-21 Exported renderings
    [mimu_batt.ipt, mimu_batt.stl, mimu_phantom.3mf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]
2022-12-22 Added Switch for drive_fallback mode
    [mimu_base.kicad_sch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]
2022-12-22 Dropped support for mimu_batt
    [mimu_batt-B_Cu.gbr, mimu_batt-B_Mask.gbr, mimu_batt-B_Paste.gbr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]
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2022-12-22 Fixed Issue #6 by mirroring TOF connector pins
    [mimu_base.kicad_sch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]
2023-01-03 Smaller fab text for printing cheat-sheet
    [mimu_phantom.kicad_pcb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]
2023-01-08 Fixed pin numbers
2023-01-10 Crash at sensor.init()
2023-01-10 Enabled O2 optimizations: Mainly funcion inlining. This way, it is actually able to use the sensor
2023-01-10 With small Wire lib and original pololu lib it seems to accurately measure things
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2023-01-12 Made patch applyable.
    With this patch for *Wire*, the difference in RAM usage is huge:
    Previously:
    ```
    RAM: [=== ] 31.6% (used 162 bytes from 512 bytes)
    Flash: [========= ] 90.6% (used 7422 bytes from 8192 bytes)
    ```
    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
2023-01-13 Improved Error handling and signalling
    [main.cpp, userInterface.cpp]
2023-01-13 Fixed Overflow with large/ish fade times
    [main.cpp, peripherals.hpp]
2023-01-14 Fixed bug of debounceing causing oscillations
    [main.cpp]
2023-01-14 Allowed for occasional sensor timeouts. But why do they happen?
    Happens occasionally when switching between infinity and measureable, or inf. and switch?
2023-01-27 Removed some Debug writes
    [mimu_base.kicad_sch]
2024-01-21 Test with using the other optocoupler that needs less current
    [mimu_base.kicad_sch, mimu_phantom.kicad_sch]
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
